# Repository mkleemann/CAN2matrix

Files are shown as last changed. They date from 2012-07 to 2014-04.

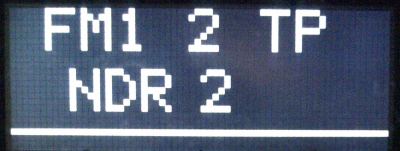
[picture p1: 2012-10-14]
doc/images/station_info.png

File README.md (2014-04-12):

####CAN2matrix - AVR based project to get information from one CAN bus to another.

Since new cars come with CAN bus to control anything, the need to use these
signals arose when trying to build in my old CAN controlled radio.

Single CAN solutions exist, but often they lack in something or other. So I
used the tips and tricks to combine such solutions.

The project initially is Atmel Studio 6 based. The build process is now
changed to use cmake. All artefacts, like makefiles, have been removed and are
no longer maintained. Documentation is being built using doxygen and dot.

To build out of source use:

```bash
mkdir -p /path/to/some/build/dir
cd /path/to/some/build/dir
cmake -DCMAKE_TOOLCHAIN_FILE=/path/to/CAN2matrix/cmake/genric-gcc-avr.cmake /path/to/CAN2matrix
make
```

For Windows use the following call instead:

```bash
cmake -G "Unix Makefiles" -DCMAKE_TOOLCHAIN_FILE=/path/to/CAN2matrix/cmake/genric-gcc-avr.cmake /path/to/CAN2matrix
```

This builds, but does not upload, the application. Use

```bash
make help
```

to get a list of all targets available, including the uploading targets.

Both CAN buses (could) use a different bitrate. Only a small number of
signals are needed to communicate between buses. Sleep and/or power down
functionality is a must, if you don't want to help your car waking up after
a weekend. Of course, if one has access to other information, one shall make
use of it.

####Current Stage:

Current state is the implementation of the dual CAN treatment. Some special
CAN ids (minimal navigation signals) are now treated and can be used with
a CAN adapter or the real target radio.

Some further testing is needed to get all information from the car CAN
bus, especially the communication to the instrument cluster. This is needed
to show some station information like the original car radio would.

Additionally bus sleep detection is working to put the connected CAN
controllers (MCP2515) to sleep. For CAN1 (master) the connected MCP2551
is not going to sleep, since it is needed for detecting CAN activity. The
slave MCP2551 is also put into sleep mode and woken up with its controller.

The AVR goes into power down mode with INT0 enabled to wake it up (wake on
CAN activity).

Note: Only standard CAN frames are supported right now.

####Next Steps/Ideas:

(M)andatory
(O)ptional
(S)tarted Implementation
(P)artly Implemented
(T)esting and Optimizing
(D)one

- (D) Power Down (all chips including AVR) by CAN bus sleep
- (D) Wake Up by CAN activity on the (master) bus (MCP2551/MCP2515)
- (D) Wake Up by CAN activity for AVR itself
- (D) Implement "The CAN Matrix" in code
- (D) dim unit using a light dependent resistor
- (S) implement CAN message filtering to get only IDs used
- (D) implement (simple) CAN error treatment/signalling
- (O) EEPROM use for message matrix
- (O) implement support for extended CAN frames
- (O) implement communication with instrument cluster

####Postponed or different projects

- PDC distance showed by LEDs (see PDCViewer project)
- PDC distance showed by Video In of the unit, e.g. using MAX7456
- make use of other AVRs to include CAN2analog or Analog2CAN possibility
- turn lights using fog lights with fade out

Have fun!

M.

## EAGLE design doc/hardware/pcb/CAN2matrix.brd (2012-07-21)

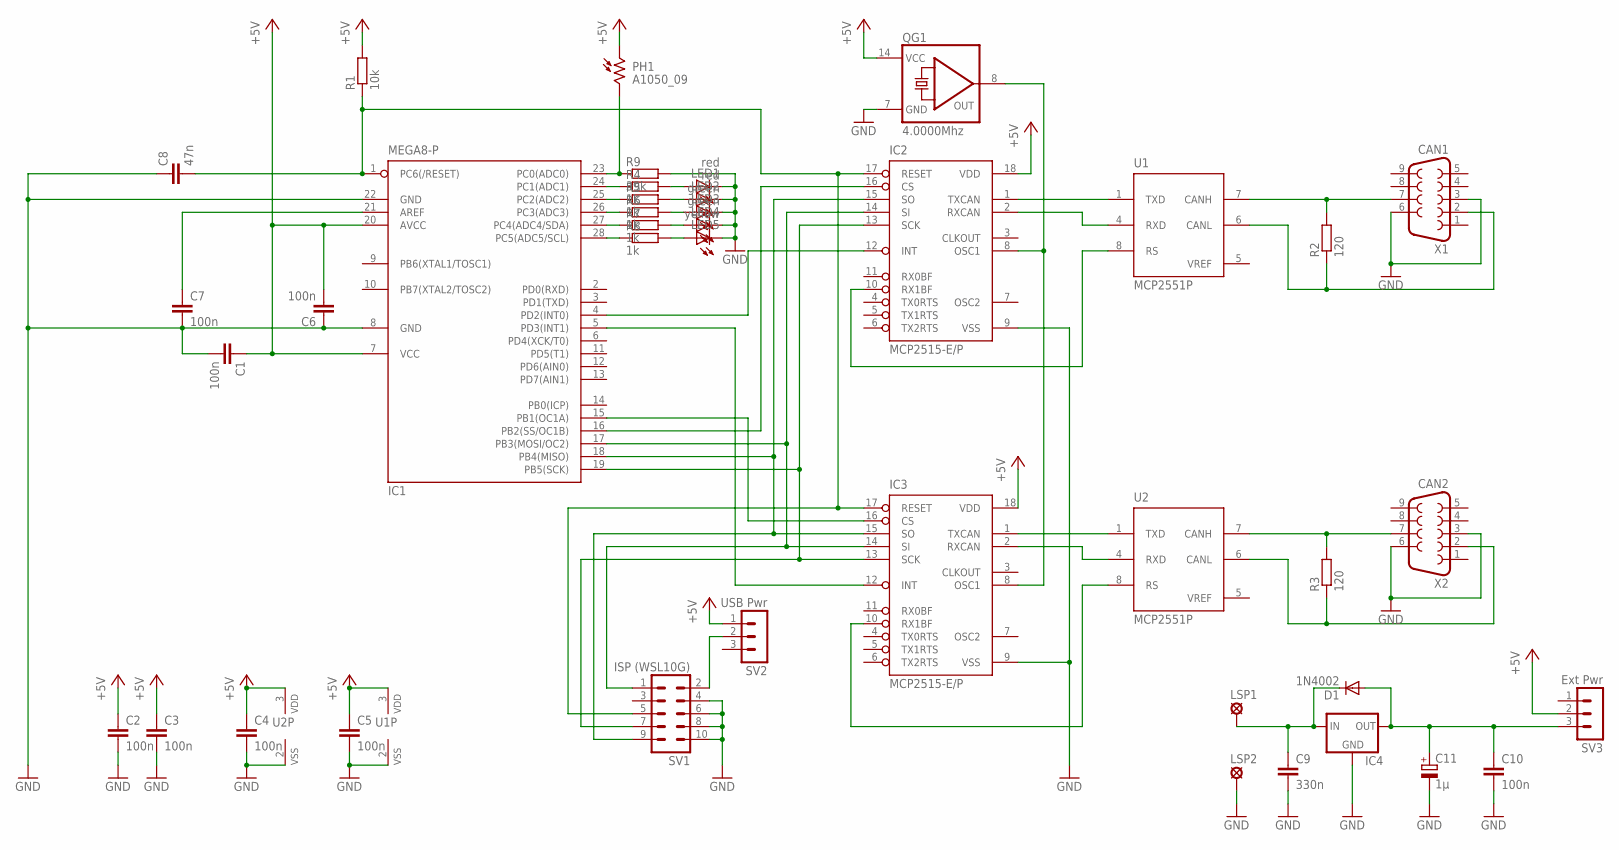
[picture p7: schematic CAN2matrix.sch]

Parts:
C1, C2, C3, C4, C5, C6, C7, C10: 100n; C050-025X075
C8: 47n; C050-025X075
C9: 330n; C050-025X075
C11: 1µ; E2,5-7
D1: 1N4002; DO41-10
IC1: MEGA8-P; DIL28-3
IC2, IC3: MCP2515-E/P; DIL18
IC4: 78LXX
LED1, LED2: red; LED3MM
LED3, LED4: green; LED3MM
LED5: yellow; LED3MM
LSP1: +12V; SE14
LSP2: SE14
PH1: A1050_09; T0-46-A10XX
QG1: 4.0000Mhz; DIL14S
R1: 10k; 0207/2V
R2, R3: 120; 0207/2V
R4, R5, R6, R7, R8: 1k; 0207/10
R9: 39k; 0204/7
SV1: ISP (WSL10G); ML10
SV2: USB Pwr; MA03-1
SV3: Ext Pwr; MA03-1
U1, U2: MCP2551P; DIL8
X1: CAN1; F09HP
X2: CAN2; F09HP

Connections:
+5V: C1.1, C2.1, C3.1, C4.1, C5.1, C6.2, IC1.7 (VCC), IC1.20 (AVCC), IC2.18 (VDD), IC3.18 (VDD), PH1.1, QG1.14 (VCC), R1.2, SV2.1, SV3.2, U1.3 (VDD), U2.3 (VDD)
+12V: C9.1, D1.C, IC4.IN, LSP1.MP
GND: C1.2, C2.2, C3.2, C4.2, C5.2, C6.1, C7.2, C8.1, C9.2, C10.2, C11.-, IC1.8 (GND), IC1.22 (GND), IC2.9 (VSS), IC3.9 (VSS), IC4.GND, LED1.K (C), LED2.K (C), LED3.K (C), LED4.K (C), LED5.K (C), LSP2.MP, QG1.7 (GND), R9.2, SV1.4, SV1.6, SV1.8, SV1.10, U1.2 (VSS), U2.2 (VSS), X1.3, X1.6, X2.3, X2.6
unnamed: IC1.18 (PB4(MISO)), IC2.15 (SO), IC3.15 (SO), SV1.9
unnamed: IC1.17 (PB3(MOSI/OC2)), IC2.14 (SI), IC3.14 (SI), SV1.1
unnamed: IC1.19 (PB5(SCK)), IC2.13 (SCK), IC3.13 (SCK), SV1.7
unnamed: R2.2, U1.7 (CANH), X1.7
unnamed: R3.2, U2.7 (CANH), X2.7
unnamed: R3.1, U2.6 (CANL), X2.2
unnamed: IC3.10 (RX1BF), U2.8 (RS)
unnamed: C7.1, IC1.21 (AREF)
unnamed: C8.2, IC1.1 (PC6(/RESET)), IC2.17 (RESET), IC3.17 (RESET), R1.1, SV1.5
unnamed: IC2.1 (TXCAN), U1.1 (TXD)
unnamed: IC2.2 (RXCAN), U1.4 (RXD)
unnamed: IC3.1 (TXCAN), U2.1 (TXD)
unnamed: IC3.2 (RXCAN), U2.4 (RXD)
unnamed: IC1.16 (PB2(SS/OC1B)), IC2.16 (CS)
unnamed: IC1.15 (PB1(OC1A)), IC3.16 (CS)
unnamed: IC1.4 (PD2(INT0)), IC2.12 (INT)
unnamed: IC1.5 (PD3(INT1)), IC3.12 (INT)
unnamed: IC2.8 (OSC1), IC3.8 (OSC1), QG1.8 (OUT)
unnamed: IC2.10 (RX1BF), U1.8 (RS)
unnamed: R2.1, U1.6 (CANL), X1.2
unnamed: SV1.2, SV2.2
unnamed: IC1.24 (PC1(ADC1)), R4.1
unnamed: IC1.25 (PC2(ADC2)), R5.1
unnamed: IC1.26 (PC3(ADC3)), R6.1
unnamed: IC1.27 (PC4(ADC4/SDA)), R7.1
unnamed: IC1.28 (PC5(ADC5/SCL)), R8.1
unnamed: LED1.A, R4.2
unnamed: LED2.A, R5.2
unnamed: LED3.A, R6.2
unnamed: LED4.A, R7.2
unnamed: LED5.A, R8.2
unnamed: IC1.23 (PC0(ADC0)), PH1.2, R9.1
unnamed: C10.1, C11.+, D1.A, IC4.OUT, SV3.3
VREF: U1.5 (VREF), U2.5 (VREF)

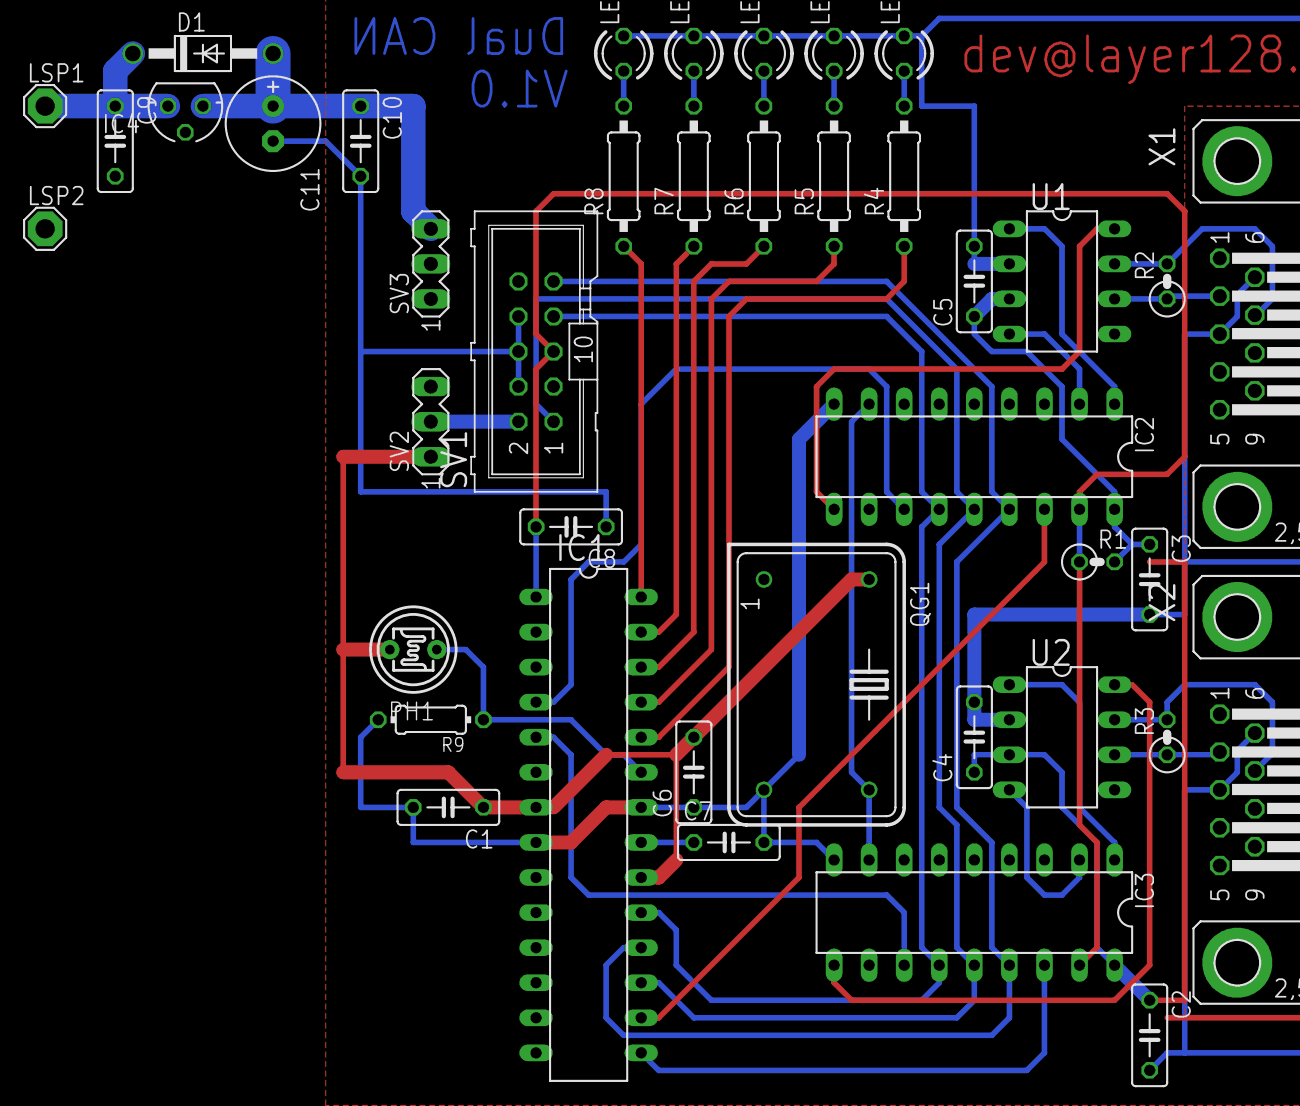
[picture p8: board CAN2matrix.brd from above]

Board: 2 copper layers, 41 parts (0 on the bottom side), 37 nets.

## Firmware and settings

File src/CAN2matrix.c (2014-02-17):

/**
 * ----------------------------------------------------------------------------
 *
 * "THE ANY BEVERAGE-WARE LICENSE" (Revision 42 - based on beer-ware license):
 * <dev@layer128.net> wrote this file. As long as you retain this notice you
 * can do whatever you want with this stuff. If we meet some day, and you think
 * this stuff is worth it, you can buy me a be(ve)er(age) in return. (I don't
 * like beer much.)
 *
 * Matthias Kleemann
 *
 * ----------------------------------------------------------------------------
 *
 * \file CAN2matrix.c
 *
 * \date Created: 28.11.2011 18:12:46
 * \author Matthias Kleemann
 **/


#include <avr/interrupt.h>
#include <avr/sleep.h>
#include <avr/cpufunc.h>
//#include <stdlib.h>

#include "can/can_mcp2515.h"
#include "adc/adc.h"
#include "comm/comm_matrix.h"
#include "leds/leds.h"
#include "timer/timer.h"
//#include "uart/uart.h"
#include "CAN2matrix.h"

//! counter to evaluate timing to send CAN messages
volatile uint8_t send_it         = 0;
//! flag to send tick to instrument cluster
volatile bool    trigger50ms     = false;
//! current state of FSM
volatile state_t fsmState        = INIT;

/**
 * \brief main loop
 * \returns nothing, since the main loop does not end until power off
 *
 * The main loop consists of the FSM and calls all necessary init sequences
 * before entering it. Any error in the init process will result in
 * entering the error state. This is indicated by a blinking LED.
 **/
#ifdef __DOXYGEN__
int main(void)
#else
int __attribute__((OS_main)) main(void)
#endif
{
   initHardware();

   if (true == initCAN())
   {
      // start timers and enable ADC
      startTimer1();
      startTimer2();
      adc_enable();
      // start normal operation
      fsmState = RUNNING;

      led_on(sleepLed);

      // enable all (configured) interrupts
      sei();

      while (1)
      {
         switch (fsmState)
         {
            case RUNNING:
            {
               run();
               break;
            }

            case WAKEUP:
            {
               wakeUp();
               fsmState = RUNNING;
               break;
            }

            case SLEEP_DETECTED:
            {
               sleepDetected();
               fsmState = SLEEPING;
               break;
            }

            case SLEEPING:
            {
               sleeping();
               // set state WAKEUP here, too avoid race conditions
               // with pending interrupt
               fsmState = WAKEUP;
               break;
            }

            default:
            {
               errorState();
               fsmState = ERROR;
               break;
            }
         }
      }
   }

   errorState();
}


/***************************************************************************/
/* STATES OF FSM                                                           */
/***************************************************************************/

/**
 * @brief Deactivate CAN and timers
 *
 * Sleep trigger was detected (no CAN activity on master bus). All timers are
 * stopped and ADC disabled. CAN controllers are put to sleep and AVR is
 * preparing for sleep mode.
 */
void sleepDetected()
{
   // stop timer for now
   stopTimer1();
   stopTimer2();

   // stop adc to save power
   adc_disable();

#ifdef ___TEST_TX_ABORT__
   // abort any pending CAN frames to be transmitted on CAN
   can_abort_all_transmissions(CAN_CHIP1);
   // wait for SPI
   _delay_ms(1);
   can_abort_all_transmissions(CAN_CHIP2);
#endif

   // (re)set global flags
   send_it  = 0;

   // put MCP25* to sleep for CAN2 and activate after activity on CAN1
   // This has to be done before master CAN goes to sleep, because
   // the clock of the slave chip may be taken from master CAN chip's
   // CLKOUT pin.
   mcp2515_sleep(CAN_CHIP2, INT_SLEEP_MANUAL_WAKEUP);
   // wait for SPI
   _delay_ms(1);

   // put MCP2515 to sleep and wait for activity interrupt
   mcp2515_sleep(CAN_CHIP1, INT_SLEEP_WAKEUP_BY_CAN);

   // low power consumption
   led_all_off();
}

/**
 * @brief enter AVR sleep mode
 *
 * AVR enters sleep mode and also wakes up in this state, so some intial
 * steps to set wakeup interrupt need to be done here.
 *
 * The three \c _NOP(); instructions are a safety, since older AVRs may
 * skip the next couple of instructions after sleep mode.
 *
 * Also a precaution is the disabling of the wake up interrupt, to avoid
 * several interrupts to happen, if the signal lies too long on the
 * external interrupt pin.
 */
void sleeping()
{
   cli();

   // enable wakeup interrupt INT0
   GICR  |= EXTERNAL_INT0_ENABLE;

   // let's sleep...
   set_sleep_mode(AVR_SLEEP_MODE);
   // sleep_mode() has a possible race condition in it, so splitting it
   sleep_enable();
   sei();
   sleep_cpu();
   sleep_disable();

   // just in case...
   _NOP();
   _NOP();
   _NOP();

   // disable interrupt: precaution, if signal lies too long on pin
   GICR  &= ~(EXTERNAL_INT0_ENABLE);
}

/**
 * @brief wake up CAN and reinitialize the timers
 *
 * Now the AVR has woken up. Timers needs to be restarted, ADC to be enabled
 * again and the CAN controllers will also need to enter their working mode.
 */
void wakeUp()
{
   cli();
   // wakeup all CAN busses
   mcp2515_wakeup(CAN_CHIP1, INT_SLEEP_WAKEUP_BY_CAN);
   // wait a little for the CAN controller to be ready (Tosc * 128)
   _delay_ms(1);
   mcp2515_wakeup(CAN_CHIP2, INT_SLEEP_MANUAL_WAKEUP);
   // wait a little for the CAN controller to be ready (Tosc * 128)
   _delay_ms(1);

   restartTimer1();
   restartTimer2();

   adc_enable();

   sei();

   // debugging ;-)
   led_on(sleepLed);
}

/**
 * @brief do all the work.
 */
void run()
{
   can_t msg;
   can_error_t error;

   /**** GET MESSAGES FROM CAN1 ***********************************/

   handleCan1Reception(&msg);
   _delay_ms(1);

   /**** PUT MESSAGES TO CAN2 *************************************/

   handleCan2Transmission(&msg);
   _delay_ms(1);

   /**** GET MESSAGES FROM CAN2 ***********************************/

   handleCan2Reception(&msg);
   _delay_ms(1);

   /**** PUT MESSAGES TO CAN1 *************************************/

   handleCan1Transmission(&msg);
   _delay_ms(1);

   /**** CHECK CAN STATUS *****************************************/
   error = can_get_general_bus_errors(CAN_CHIP1);
   if(CAN_ERR_NO_ERROR == error)
   {
      led_off(errCan1LED);
   }
   else
   {
      led_on(errCan1LED);
   }

   error = can_get_general_bus_errors(CAN_CHIP2);
   if(CAN_ERR_NO_ERROR == error)
   {
      led_off(errCan2LED);
   }
   else
   {
      led_on(errCan2LED);
   }
}

/**
 * @brief Error state
 *
 * Call this when an illegal state is reached. Only some status LEDs will
 * blink to show the error, but the system stops to work.
 */
void errorState()
{
   // error handling, e.g. init failed
   stopTimer1();
   restartTimer2();     // may be stopped, due to sleep mode
   while (1)
   {
      if (0 == (trigger50ms % 10))  // approx. 500ms
      {
         trigger50ms = false;
         led_toggle(sleepLed);
      }
   }
}

/**
 * @brief Initialize Hardware
 *
 * Setting up the peripherals to the AVR and the wake-up interrupt
 * trigger.
 *
 * * \ref page_timers to trigger events
 *
 * * \ref page_spi to communicate to the MCP2515
 *
 * * \ref page_status_leds to show the (non-)errors of your way
 *
 * * \ref page_adc for connecting the analog and digital world
 */
void initHardware()
{
   // init LED output
   led_init();

   // set timer for bussleep detection
   initTimer1(TimerCompare);

   // set timer for CAN 100ms trigger
   initTimer2(TimerCompare);

   // initialize the hardware SPI with default values set in spi/spi_config.h
   spi_pin_init();
   spi_master_init();

   // initialize adc
   adc_init();

   // initialize uart
//   uart_init();

   // set wakeup interrupt trigger on low level
   MCUCR |= EXTERNAL_INT0_TRIGGER;
}

/**
 * @brief Initialize the CAN controllers
 *
 * Calls can_init_mcp2515 for each attached CAN controller and setting up
 * bit rate. If an error occurs some status LEDs will indicate it.
 *
 * See chapter \ref page_can_bus for further details.
 *
 * @return true if all is ok. Otherwise false is returned.
 */
bool initCAN()
{
   bool retVal = true;

   // init can interface 1
   if (false == can_init_mcp2515(CAN_CHIP1, CAN_BITRATE_100_KBPS, NORMAL_MODE))
   {
      // signal error on initialization
      led_on(errCan1LED);
      retVal = false;
   }
   // wait for SPI
   _delay_ms(1);
   // init can interface 2
   if (false == can_init_mcp2515(CAN_CHIP2, CAN_BITRATE_125_KBPS, NORMAL_MODE))
   {
      // signal error on initialization
      led_on(errCan2LED);
      retVal = false;
   }

   return retVal;
}


/***************************************************************************/
/* INTERRUPT SERVICE ROUTINES                                              */
/***************************************************************************/

/**
 * @brief interrupt service routine for Timer1 capture
 *
 * Timer1 input capture interrupt (~15s 4MHz@1024 prescale factor)
 **/
ISR(TIMER1_CAPT_vect)
{
   fsmState = SLEEP_DETECTED;
}

/**
 * @brief interrupt service routine for Timer2 compare
 *
 * Timer2 compare match interrupt handler --> set as 25ms (4x25ms = 100ms)
 **/
ISR(TIMER2_COMP_vect)
{
   ++send_it;
   trigger50ms = (0 == (send_it % 2));   // ~50ms;
}

/**
 * @brief interrupt service routine for external interrupt 0
 *
 * External Interrupt0 handler to wake up from CAN activity
 **/
ISR(INT0_vect)
{
   // needs to be here, even if empty
}

/***************************************************************************/
/* HELPER ROUTINES                                                         */
/***************************************************************************/

/**
 * @brief handles CAN1 reception
 * @param msg - pointer to message struct
 */
void handleCan1Reception(can_t* msg)
{
   if (can_check_message_received(CAN_CHIP1))
   {
      // try to read message
      if (can_get_message(CAN_CHIP1, msg))
      {
         // reset timer counter, since there is activity on master CAN bus
         setTimer1Count(0);

         // fetch information from CAN1
         fetchInfoFromCAN1(msg);

         // signal activity
         led_toggle(rxCan1LED);
      }
   }
}

/**
 * @brief handles CAN2 reception
 * @param msg - pointer to message struct
 */
void handleCan2Reception(can_t* msg)
{
   // empty read buffers and get information
   if (can_check_message_received(CAN_CHIP2))
   {
      // try to read message
      if (can_get_message(CAN_CHIP2, msg))
      {
         // fetch information from CAN2
         fetchInfoFromCAN2(msg);
      }
   }
}

/**
 * @brief handle CAN1 transmission
 * @param msg - pointer to message struct
 */
void handleCan1Transmission(can_t* msg)
{
   // handle reset trigger wisely, when putting in some code here!
}

/**
 * @brief handle CAN2 transmission
 * @param msg - pointer to message struct
 */
void handleCan2Transmission(can_t* msg)
{
   if(true == trigger50ms)
   {
      trigger50ms = false;
      // signal activity
      led_toggle(txCan2LED);
      sendCan2(msg);
      // sample and set dim value
      uint16_t dimValue = adc_get();
      setDimValue(dimValue);
   }
}

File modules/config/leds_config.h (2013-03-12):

/**
 * ----------------------------------------------------------------------------
 *
 * "THE ANY BEVERAGE-WARE LICENSE" (Revision 42 - based on beer-ware license):
 * <dev@layer128.net> wrote this file. As long as you retain this notice you
 * can do whatever you want with this stuff. If we meet some day, and you think
 * this stuff is worth it, you can buy me a be(ve)er(age) in return. (I don't
 * like beer much.)
 *
 * Matthias Kleemann
 *
 * ----------------------------------------------------------------------------
 *
 * \file leds_config.h
 *
 * \date Created: 28.11.2011 18:18:23
 * \author Matthias Kleemann
 **/


#ifndef LEDS_CONFIG_H_
#define LEDS_CONFIG_H_

/**
 * \enum eLED
 * \brief define LEDs connected to your controller
 *
 * Name them as you wish, but keep in mind that it matches the
 * port/pin definitions below.
 */
typedef enum
{
   //! error on CAN1
   errCan1LED  = 0,
   //! error on CAN2
   errCan2LED  = 1,
   //! tx traffic on CAN2
   txCan2LED   = 2,
   //! rx traffic on CAN1
   rxCan1LED   = 3,
   //! status LED for run/sleep mode
   sleepLed    = 4,
   //! maximum number of LEDs
   NUM_OF_LEDS = 5         // always the last one
} eLED;

/**
 * \def P_LEDS
 * \brief defines for global array to access port pins directly via port address
 *
 * Note: The definitions here correspond to the LED names in eLED. They also
 *       correspond to the type definition of ledType in leds.h.
 */
#define P_LEDS    SET_PORT_PTR(C,1), \
                  SET_PORT_PTR(C,2), \
                  SET_PORT_PTR(C,3), \
                  SET_PORT_PTR(C,4), \
                  SET_PORT_PTR(C,5)

#endif /* LEDS_CONFIG_H_ */

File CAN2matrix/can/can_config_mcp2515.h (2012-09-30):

/**
 * ----------------------------------------------------------------------------
 *
 * "THE ANY BEVERAGE-WARE LICENSE" (Revision 42 - based on beer-ware license):
 * <dev@layer128.net> wrote this file. As long as you retain this notice you
 * can do whatever you want with this stuff. If we meet some day, and you think
 * this stuff is worth it, you can buy me a be(ve)er(age) in return. (I don't
 * like beer much.)
 *
 * Matthias Kleemann
 *
 * ----------------------------------------------------------------------------
 *
 * \file can_config_mcp2515.h
 *
 * Here you can add the configuration(s) you need. Some of them are not
 * to be changed without the need of adapting the code itself. Most likely
 * any type definitions you find here.
 *
 * \date Created: 28.11.2011 18:35:54
 * \author Matthias Kleemann
 **/



#ifndef CAN_CONFIG_MCP2515_H_
#define CAN_CONFIG_MCP2515_H_

/**************************************************************************/
/* TYPEDEFINITIONS                                                        */
/*                                                                        */
/* Note: Add here what you need to add, but keep the naming scheme the    */
/*       same. You may need to adapt the source - so be careful.          */
/**************************************************************************/

/**
 * \addtogroup mcp_init CAN Controller Init Functions
 * CAN controller initialisation.
 * @{
 */

/**
 * \brief index of MCP2515 chips connected
 *
 * Any adaption here may need to adapt the source. If you keep the naming
 * scheme like CAN_CHIPx, it's easier because of macros using the definitions.
 */
typedef enum
{
   //! chip 1 (master CAN)
   CAN_CHIP1      = 0,
   //! chip 2 (slave CAN)
   CAN_CHIP2      = 1,
   //! always the last one!
   NUM_OF_MCP2515 = 2
} eChipSelect;


/**************************************************************************/
/* SETTINGS                                                               */
/**************************************************************************/

// Port definitions to access the defined MCP2515

/**
 * \def CHIP1_CS_PIN
 * \brief chip select pin of CAN controller 1
 *
 * \def CHIP1_INT_PIN
 * \brief (receive) interrupt pin of CAN controller 1
 */
#define CHIP1_CS_PIN       B,2
#define CHIP1_INT_PIN      D,2

/**
 * \def CHIP2_CS_PIN
 * \brief chip select pin of CAN controller 2
 *
 * \def CHIP2_INT_PIN
 * \brief (receive) interrupt pin of CAN controller 2
 */
#define CHIP2_CS_PIN       B,1
#define CHIP2_INT_PIN      D,3

/*! @} */

#endif /* CAN_CONFIG_MCP2515_H_ */

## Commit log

2012-03-16 rework adc documentation
2012-03-22 add more comments to avoid warnings by doxygen
    [CAN2matrix.c]
2012-03-22 rework and correct documentation for LEDs
    [leds_config.h]
2012-04-02 documentation of SPI section
2012-04-02 some further comments on SPI register calculations
2012-04-02 add documentation of timer section
2012-04-04 intermediate stage documenting CAN module
2012-04-05 add todo in timer documentation
2012-06-19 rework dim value handling; add some test code for chip timing and possible race condition when putting AVR to sleep
    [CAN2matrix.c]
2012-06-29 add description of ADC configuration
2012-06-29 add pre-defintion __DOXYGEN__ for commenting options not currently used; add ADC option documentation
2012-07-03 redo state settings for wake-up; move disabling wake-up interrupt to avoid skipping of setup due to AVR wake-up - see _NOP()
    [CAN2matrix.c]
2012-07-04 add some wait cycles for SPI ready and changing CAN chip
2012-07-04 remove else statement to insert wait cycle; did not build
2012-07-11 change init sequence to avoid timer overflows in an early startup stage; start timers/ADC after CAN is initialized
    [CAN2matrix.c]
2012-07-16 wait for SPI before changing CAN chips
2012-07-18 remove duplicate of ADC sampling and only do it every 100ms
2012-07-21 test layout with Design Rules by Eurocircuits and change text to vector graphics - no update on images
    [CAN2matrix.brd]
2012-08-08 add documentation for currently unused definitions
2012-08-08 add documentation for currently unused definitions; further details
2012-09-07 some UART tests
2012-09-13 add parser for CAN traces for analysis; trace format of PCAN tool chain
2012-09-20 rework gear/odo/temperature signals
2012-09-23 add tracefile name to output filename anytime
2012-09-29 use sequential write to save time and memory to clear filters
2012-09-29 add filter setup and clean up of headers and documentation; change numbering of CAN error definitions
2012-09-30 add paragraph for filter setup in init function for CAN controller
2012-10-01 signal general CAN errors (TEC/REC > 96)
    [CAN2matrix.c]
2012-10-03 add FSM frame for IC communication module
2012-10-08 change setter to getter for info text to avoid circular includes
    [ic_comm.h]
2012-10-10 intermediate stage of implementation
2012-10-11 add INFO frame handling; start implementation of frame buffer handling
2012-10-12 corrections in frame generation after debugging
2012-10-12 found 9 character information in trace; document it
2012-10-17 rework text setup; intermediate stage
    [ic_comm.h]
2012-10-19 add text info to frame buffer
2012-10-19 add 2sec timer for later instrument cluster information update
2012-10-19 some changes for IC communication; intermediate stage
2012-10-19 doc: rename clamp to terminal
2012-11-01 intermediate stage for communication with instrument cluster
2012-11-02 switch interactive SVG off
2012-11-05 remove instrument cluster communication for rework of state machine
    [CAN2matrix.c]
2012-11-06 redo documentaion to avoid problems with doxygen
    [ic_comm.h]
2012-11-07 intermediate stage of new state machine and sequence handling; compiles but does not run
2012-11-07 intermediate stage of sequence implementation and documentation
2012-11-15 add timer tick, stop and restart for instrument cluster communication
2012-12-04 correct wheel signal order
2012-12-05 switch to target logic of high/low byte
2012-12-05 add first stage of media info text handling
2012-12-06 further stage in media information text handling
2012-12-07 intermediate stage for media handling - does not compile
2013-03-12 prepare to use submodules
    - prepare for use of submodules and extract configuration
    - fix include paths
    - change doxygen files for use in submodule
    - adjust doxygen reference
    - adjust gitignore
    - adjust makefiles
    - use a more general approach for chip select/interrupts in can module
    - use port structure expand macros for better configuration readability
    - centralize port access struct to utils
    [CAN2matrix.c, adc_config.h, can_config_mcp2515.h]
2013-03-12 remove subdirectories for submodule introduction
    - adc
    - bar
    - can
    - leds
    - spi
    - timer
    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
2013-03-12 add adc submodule
2013-03-12 add status led submodule
2013-03-12 add spi submodule
2013-03-12 add timer submodule
2013-03-12 add uart submodule
2013-03-15 update adc module
2013-12-25 update submodules
    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
2014-01-03 takeover settings for fuses and status messages
2014-02-17 restructure source tree
    - flatten source tree
    - adapt CMakeLists.txt
    - move submodules to new location
    [CAN2matrix.brd, CAN2matrix.sch]
2014-02-17 update submodules cmake, leds and util
2014-03-21 correct wheel tick counter
    - use delta instead of absolute value
    - test outstanding, but position keeps jumping due to
    too high values for wheel signal
2014-03-22 use absolute values again
    - calculate differences of incomming wheel signals
    - sum them for outgoing wheel signal
2014-03-22 add brightness offset for night view
    - start with 64 as default
    - daylight ok so far
    - resistor changed to 18k instead of 38k as in the schematics
    - light depending resistor varies between 7k and 180k
2014-03-22 change SPI prescaling factor to 4
    - faster SPI throughput
2014-03-22 correct rollover logic once more for wheel ticks
    - now use the correct direction for the delta calculation
    when rolling over
2014-04-12 update README
    - update current stage (working in car)
    - add future outlook
